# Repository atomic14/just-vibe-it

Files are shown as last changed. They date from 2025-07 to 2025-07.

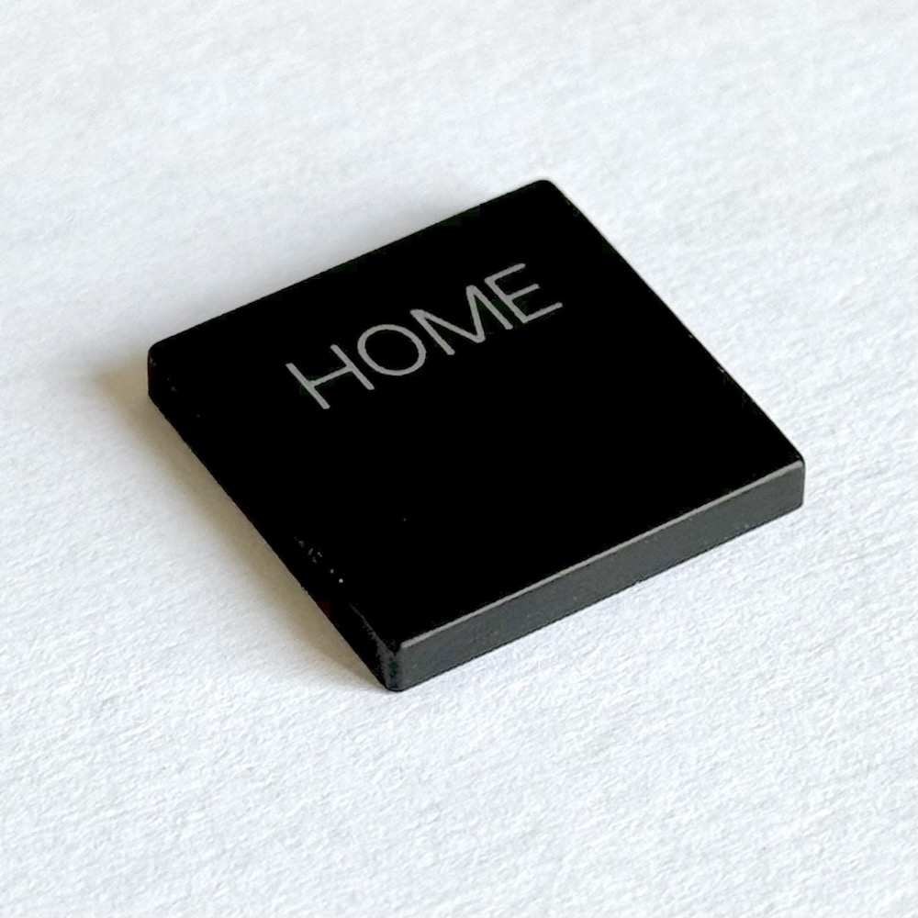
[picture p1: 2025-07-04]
hardware/Cherry_MX_ULP-main/Mistel_Air_One.jpeg

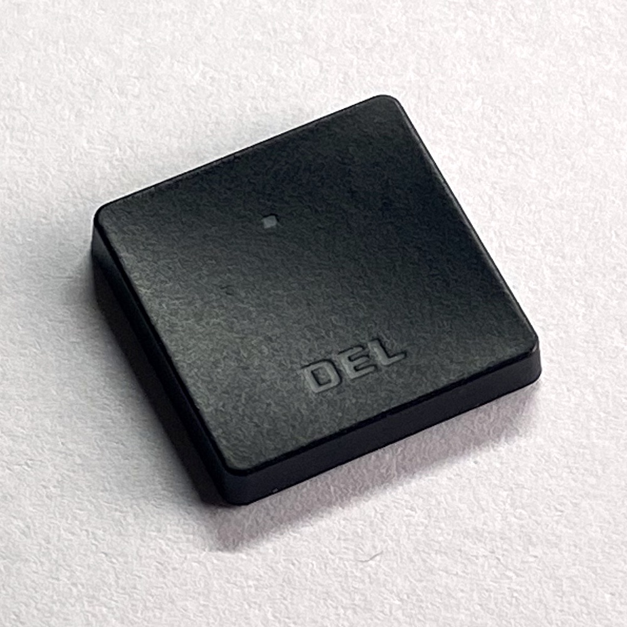
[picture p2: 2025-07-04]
hardware/Cherry_MX_ULP-main/Corsair_K100_Air.jpeg

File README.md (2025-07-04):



# Vibetastic - Single Key Keyboard

Vibetastic Demo (https://youtu.be/SV0bM1FkdLY)

*Click the image above to watch the demo video*

## Overview

A very silly but functional single-key keyboard - perfect for vibe coding! This project combines interesting hardware design choices with AI-assisted firmware development.

## Key Features

- **Dual Power Management**: Uses TPS2117 for clean switching between battery and USB power with controlled slew rate
- **Versatile Switch Compatibility**: Custom PCB footprint supports both low-profile and full-height Cherry MX switches
- **Stabilizer Support**: Full-height keycaps can use stabilizers for improved feel and reduced wobble
- **AI-Coded Firmware**: The entire codebase was developed through AI collaboration without manual code review

## Hardware Highlights

The PCB incorporates several thoughtful design decisions:
- TPS2117 power switch controller enables high capacitance loads without violating USB specifications
- Hybrid Cherry MX footprint accommodates both switch types (though stabilizers only work with full-height switches)
- Clean power management replaces traditional MOSFET/diode circuits

## Project Structure

- `/firmware/` - PlatformIO-based embedded firmware
- `/hardware/` - KiCad PCB design files and component libraries

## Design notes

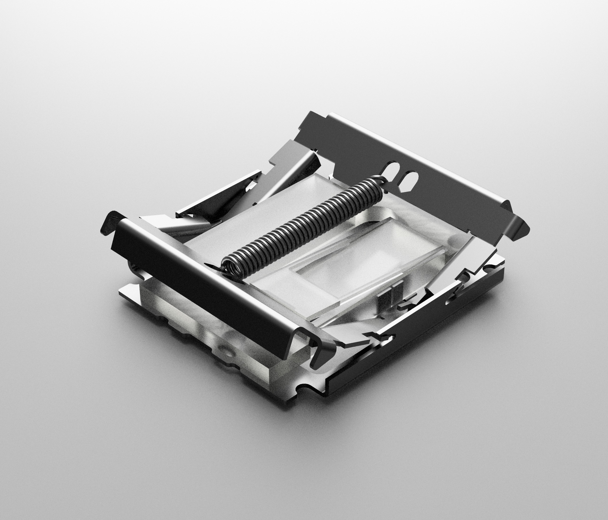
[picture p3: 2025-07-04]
hardware/Cherry_MX_ULP-main/Cherry_MX_ULP.jpg

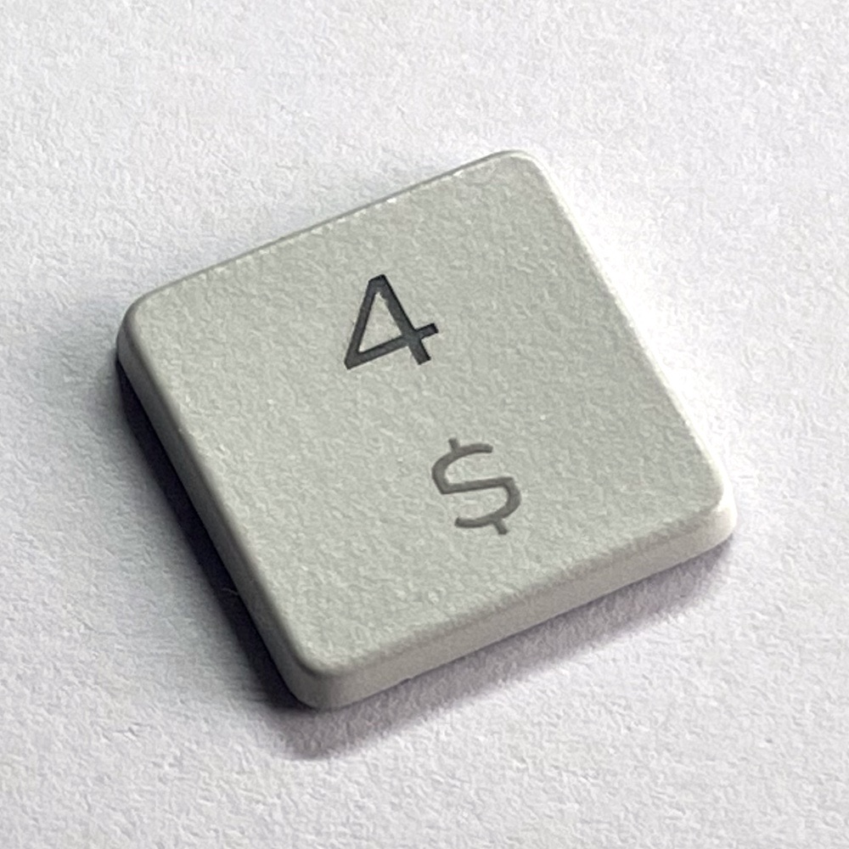
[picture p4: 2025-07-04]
hardware/Cherry_MX_ULP-main/Dell_Module.jpeg

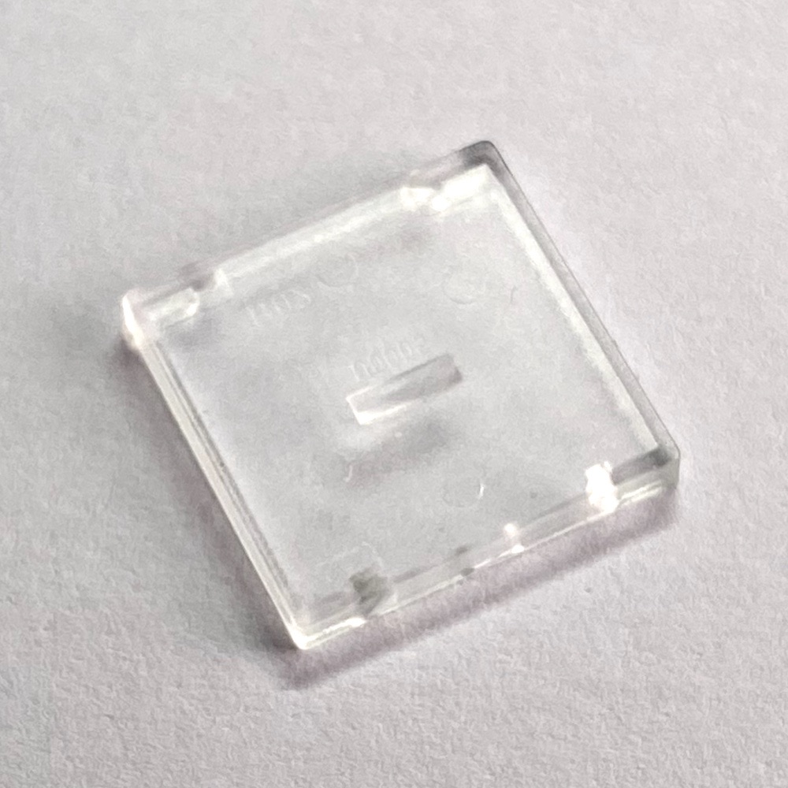
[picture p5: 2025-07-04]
hardware/Cherry_MX_ULP-main/Cherry_Early_Prototype.jpeg

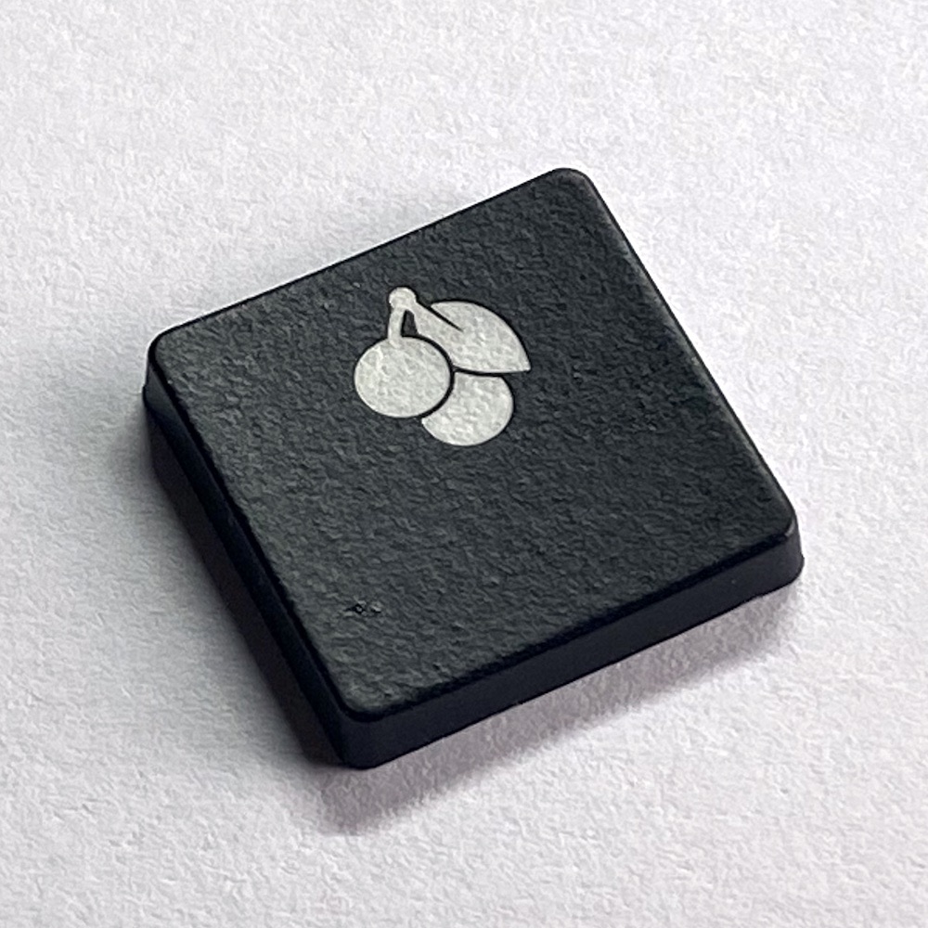
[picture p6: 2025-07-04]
hardware/Cherry_MX_ULP-main/Cherry_KW_x_ULP.jpeg

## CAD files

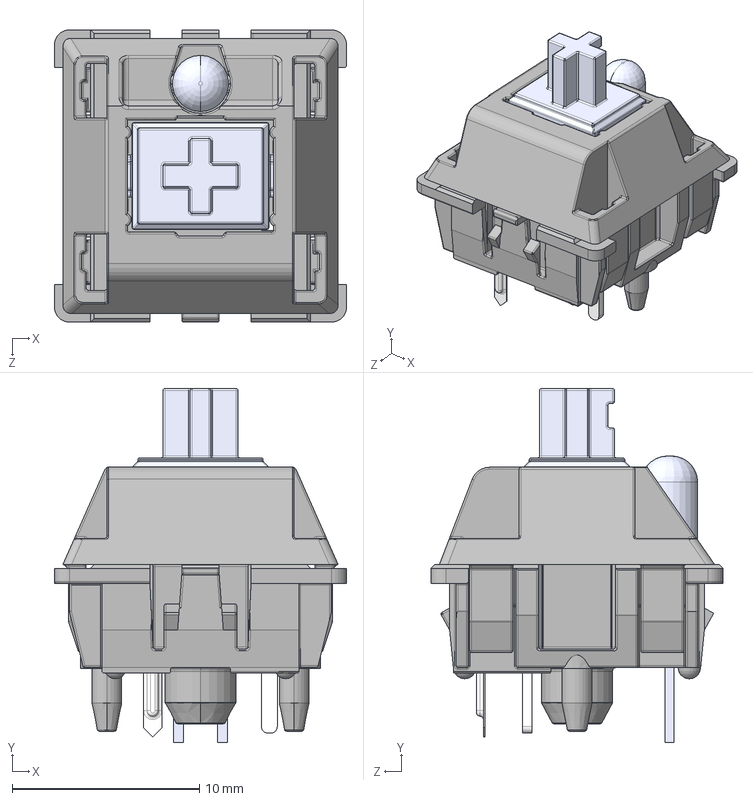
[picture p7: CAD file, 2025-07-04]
hardware/3d-models/MX .STEP
15.6 x 18.9 x 15.6 mm
MX 轴 按键′_ü___¨1
MX 轴 轴体áì_¨￠¨__
MX粣 拸簽LEDLEDLED
MX轴 轴体 底部 μ×2__默认_á2____è_
针脚___默认__è_

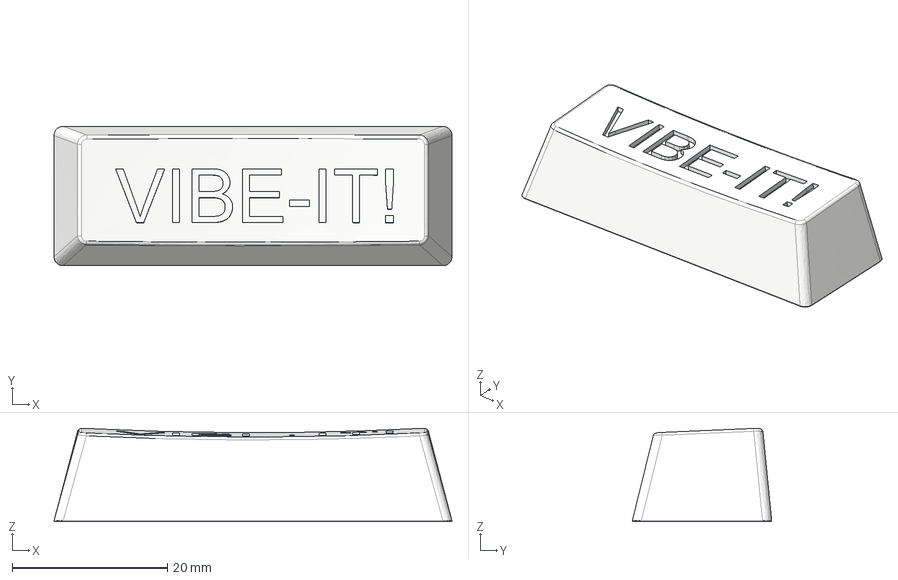
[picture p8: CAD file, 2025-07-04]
hardware/3d-models/keycap.step
51.3 x 18.0 x 12.0 mm

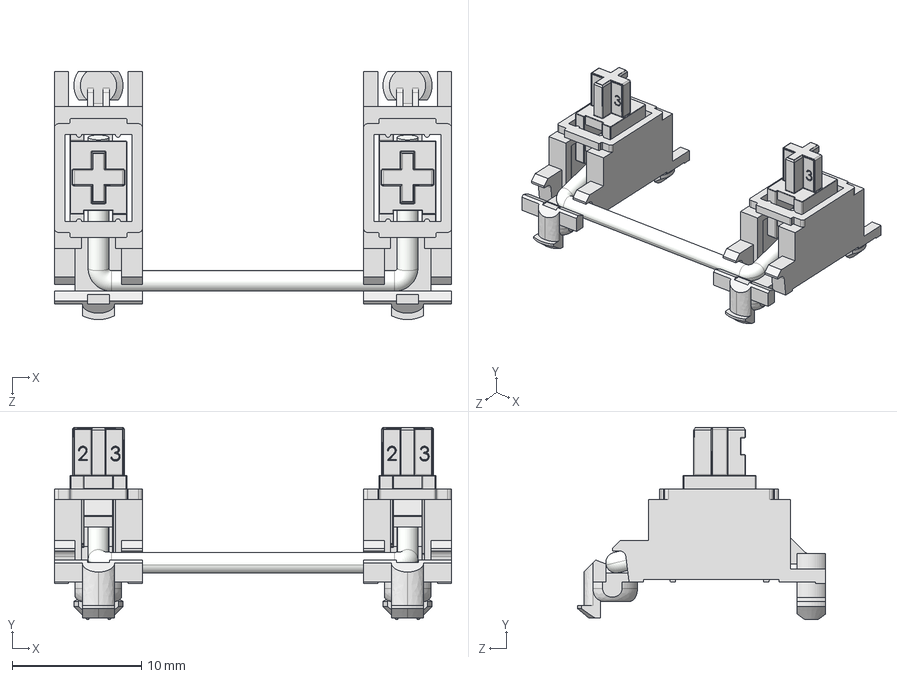
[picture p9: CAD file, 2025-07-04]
hardware/3d-models/Stabilizer - close.STEP
30.7 x 14.9 x 19.2 mm
mx Stabilizer base 16828 x 2
mx Stabilizer key 16828 x 2
metal stick 16828

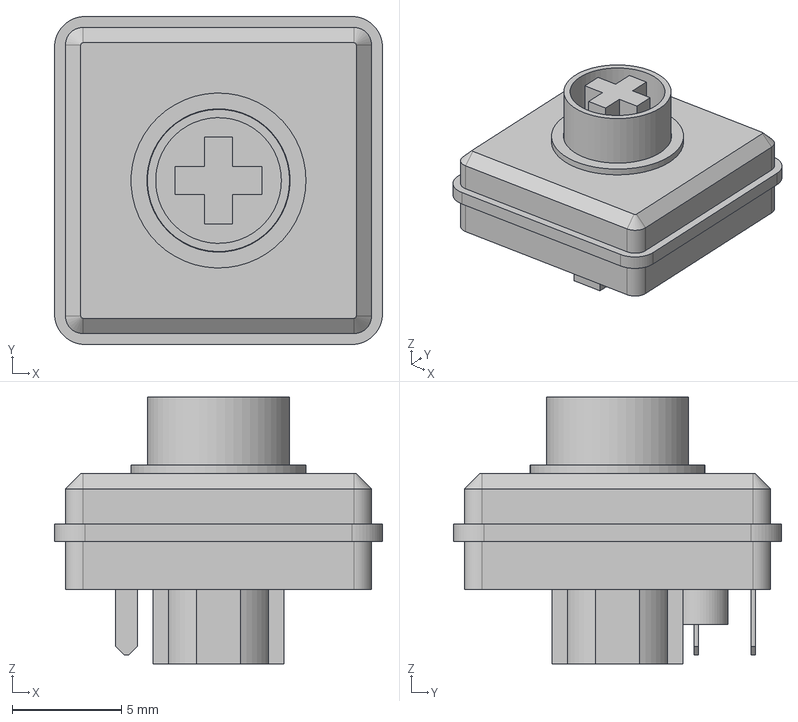
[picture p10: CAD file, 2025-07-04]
hardware/3d-models/[low detail] Low Profile Cherry MX Red.step
15.0 x 15.0 x 12.2 mm

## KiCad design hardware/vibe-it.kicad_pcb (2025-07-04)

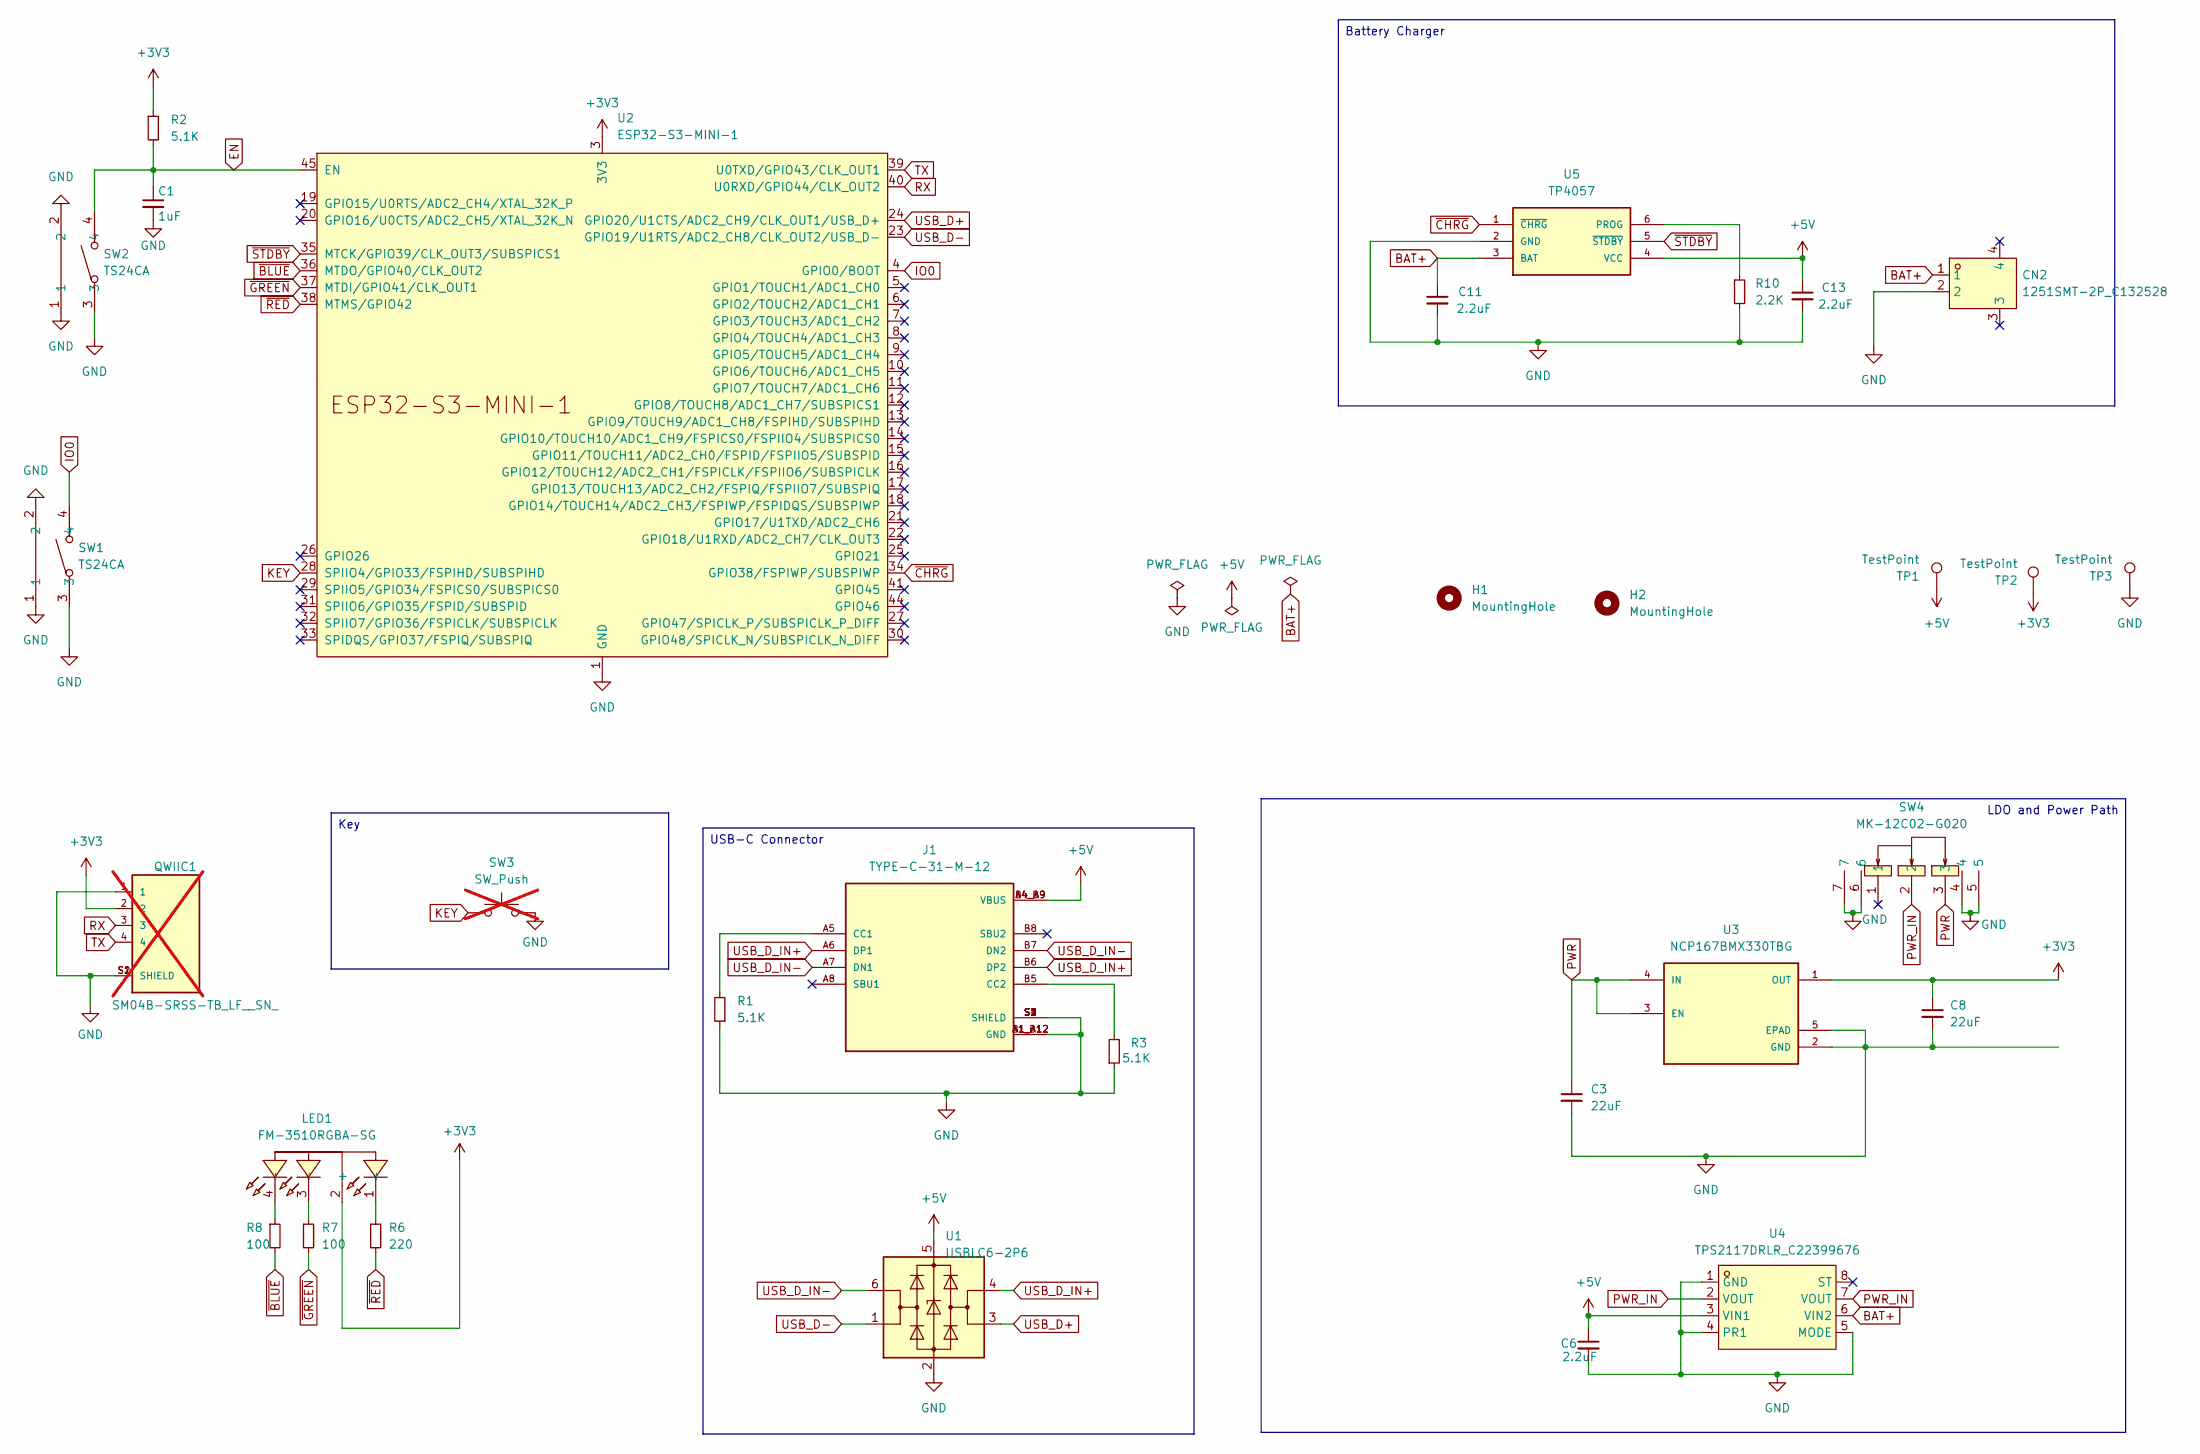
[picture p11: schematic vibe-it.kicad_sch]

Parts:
C1: 1uF; C_0603_1608Metric
C3, C8: 22uF; C_0603_1608Metric
C6: 2.2uF; C_0603_1608Metric; Mfg Part # test
C11, C13: 2.2uF; C_0603_1608Metric
CN2: 1251SMT-2P_C132528; CONN-SMD_1251SMT-2P; LCSC Part C132528
H1, H2: MountingHole; MountingHole_2.2mm_M2
J1: TYPE-C-31-M-12; HRO_TYPE-C-31-M-12; PARTREV 2020.12.08
LED1: FM-3510RGBA-SG; LED-SMD_FM-3510RGBA-SG; LCSC Part C727903
QWIIC1: SM04B-SRSS-TB_LF__SN_; JST_SM04B-SRSS-TB_LF__SN_; not fitted
R1, R2, R3: 5.1K; R_0603_1608Metric
R6: 220; R_0603_1608Metric
R7, R8: 100; R_0603_1608Metric
R10: 2.2K; R_0603_1608Metric
SW1, SW2: TS24CA; SW-SMD_TS24CA; LCSC Part C393942
SW3: SW_Push; Cherry-combined-low-mx; not fitted
SW4: MK-12C02-G020; SW-SMD_MK-12C02-G020; LCSC Part C963206
TP1, TP2, TP3: TestPoint; TestPoint_Pad_D2.0mm
U1: USBLC6-2P6; SOT-666
U2: ESP32-S3-MINI-1
U3: NCP167BMX330TBG; VREG_NCP167BMX330TBG; PARTREV 5
U4: TPS2117DRLR_C22399676; SOT-583-8; LCSC Part C22399676
U5: TP4057; SOT-23-6

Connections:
+3V3: C8.1, LED1.2 (+), QWIIC1.2, R2.1, TP2.1, U2.3 (3V3), U3.1 (OUT)
+5V: C6.1, C13.1, J1.A4_B9 (VBUS), J1.B4_A9 (VBUS), TP1.1, U1.5 (VBUS), U4.3 (VIN1), U5.4 (VCC)
BAT+: C11.1, CN2.1, U4.6 (VIN2), U5.3 (BAT)
EN: C1.1, R2.2, SW2.4, U2.45 (EN)
GND: C1.2, C3.2, C6.2, C8.2, C11.2, C13.2, CN2.2, J1.A1_B12 (GND), J1.B1_A12 (GND), J1.S1 (SHIELD), J1.S2 (SHIELD), J1.S3 (SHIELD), J1.S4 (SHIELD), QWIIC1.1, QWIIC1.S1 (SHIELD), QWIIC1.S2 (SHIELD), R1.1, R3.1, R10.2, SW1.1, SW1.2, SW1.3, SW2.1, SW2.2, SW2.3, SW3.2, SW4.4, SW4.5, SW4.6, SW4.7, TP3.1, U1.2 (GND), U2.1 (GND), U2.2 (GND), U2.42 (GND), U2.43 (GND), U2.46 (GND), U2.47 (GND), U2.48 (GND), U2.49 (GND), U2.50 (GND), U2.51 (GND), U2.52 (GND), U2.53 (GND), U2.54 (GND), U2.55 (GND), U2.56 (GND), U2.57 (GND), U2.58 (GND), U2.59 (GND), U2.60 (GND), U2.61 (GND), U2.62 (GND), U2.63 (GND), U2.64 (GND), U2.65 (GND), U3.2 (GND), U3.5 (EPAD), U4.1 (GND), U4.4 (PR1), U4.5 (MODE), U5.2 (GND)
IO0: SW1.4, U2.4 (GPIO0/BOOT)
KEY: SW3.1, U2.28 (SPIIO4/GPIO33/FSPIHD/SUBSPIHD)
unnamed: J1.A5 (CC1), R1.2
unnamed: J1.B5 (CC2), R3.2
unnamed: LED1.1 (-), R6.1
unnamed: LED1.3 (-), R7.1
unnamed: LED1.4 (-), R8.1
unnamed: R10.1, U5.6 (PROG)
PWR: C3.1, SW4.3, U3.3 (EN), U3.4 (IN)
PWR_IN: SW4.2, U4.2 (VOUT), U4.7 (VOUT)
RX: QWIIC1.3, U2.40 (U0RXD/GPIO44/CLK_OUT2)
TX: QWIIC1.4, U2.39 (U0TXD/GPIO43/CLK_OUT1)
USB_D+: U1.3 (I/O2), U2.24 (GPIO20/U1CTS/ADC2_CH9/CLK_OUT1/USB_D+)
USB_D-: U1.1 (I/O1), U2.23 (GPIO19/U1RTS/ADC2_CH8/CLK_OUT2/USB_D-)
USB_D_IN+: J1.A6 (DP1), J1.B6 (DP2), U1.4 (I/O2)
USB_D_IN-: J1.A7 (DN1), J1.B7 (DN2), U1.6 (I/O1)
~BLUE: R8.2, U2.36 (MTDO/GPIO40/CLK_OUT2)
~CHRG: U2.34 (GPIO38/FSPIWP/SUBSPIWP), U5.1 (~CHRG)
~GREEN: R7.2, U2.37 (MTDI/GPIO41/CLK_OUT1)
~RED: R6.2, U2.38 (MTMS/GPIO42)
~STDBY: U2.35 (MTCK/GPIO39/CLK_OUT3/SUBSPICS1), U5.5 (~STDBY)

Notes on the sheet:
LDO and Power Path
Battery Charger
USB-C Connector
Key

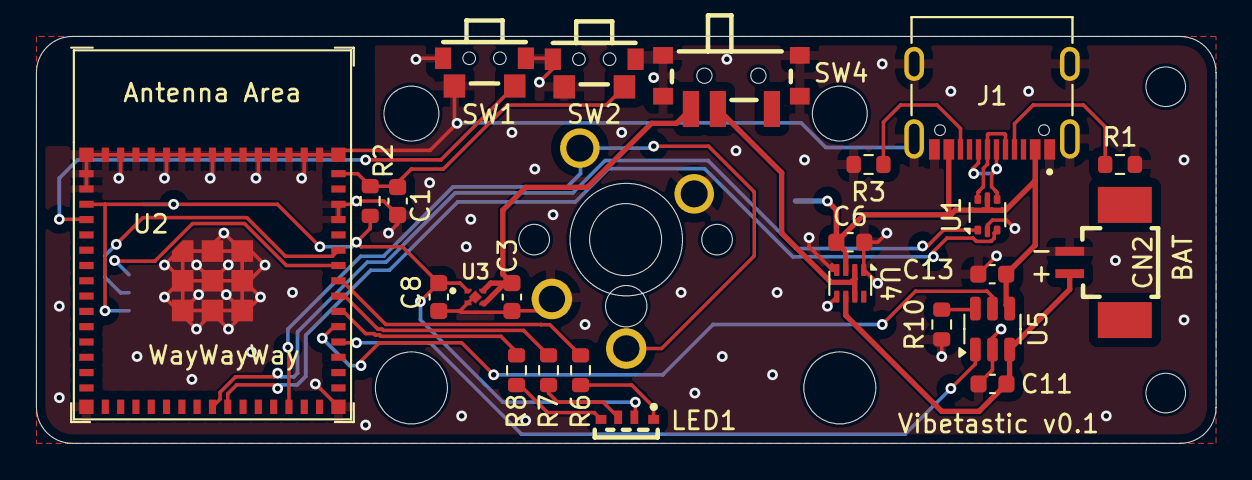
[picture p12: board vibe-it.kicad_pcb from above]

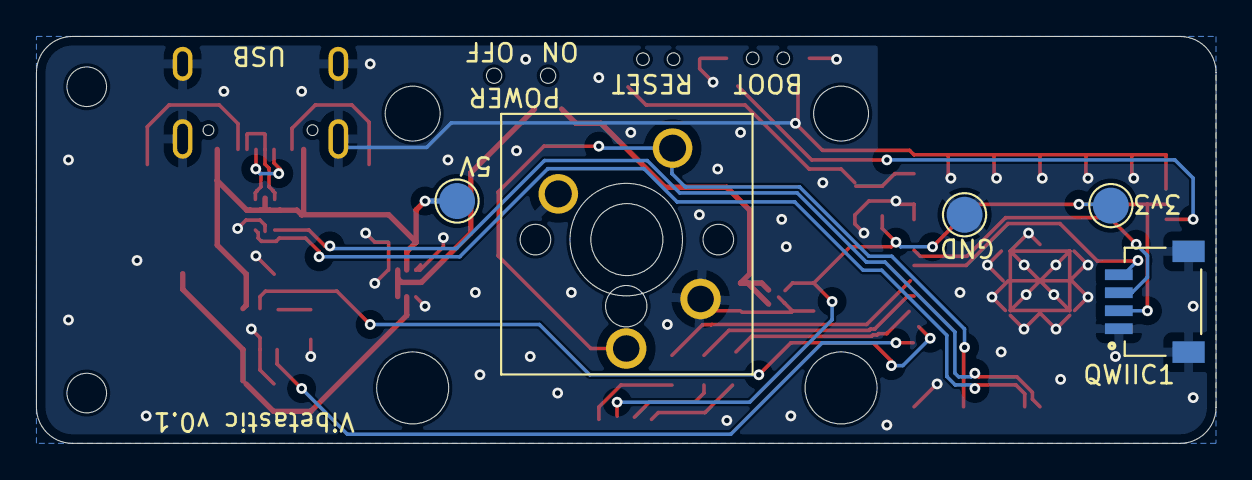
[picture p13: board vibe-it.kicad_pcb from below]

Board: 2 copper layers, 65.5 x 22.6 mm, 31 parts (5 on the bottom side), 26 nets.

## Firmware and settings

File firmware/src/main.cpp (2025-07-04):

#include <Arduino.h>
#include "hardware.h"
#include "USB.h"
#include "USBCDC.h"

// Include our custom classes
#include "ChargingStatusManager.h"
#include "KeyboardManager.h"
#include "ButtonManager.h"
#include "LEDManager.h"

// Create USB Serial instance
USBCDC SerialUSB;

// Create instances of our managers
ChargingStatusManager chargingManager;
KeyboardManager keyboardManager;
ButtonManager buttonManager;
LEDManager ledManager;

// Key state tracking
bool keysPressed = false;

void setup() {
    // Initialize USB and Serial for debugging
    USB.begin();
    SerialUSB.begin(115200);
    delay(5000); // Give serial time to initialize
    
    SerialUSB.println("=== INITIALIZING VIBETASTIC KEYBOARD ===");
    
    // Initialize all managers
    chargingManager.begin();
    keyboardManager.begin();
    buttonManager.begin();
    ledManager.begin();
    
    SerialUSB.println("=== DUAL MODE KEYBOARD READY ===");
    SerialUSB.println("USB: Always ready when plugged in");
    SerialUSB.println("BLE: Look for 'Vibetastic Keyboard' in Bluetooth settings");
    SerialUSB.println("Press and hold the key to send Command+ENTER on both USB and BLE");
    SerialUSB.println("LED Status:");
    SerialUSB.println("  Red (flashing) = Charging battery");
    SerialUSB.println("  Green (solid) = Battery fully charged");
    SerialUSB.println("  Blue (solid) = Key press indicator");
    SerialUSB.println("  Blue (3 flashes) = Startup complete");
    
    // Show ready indicator
    ledManager.showReadyIndicator();
    
    SerialUSB.println("Setup complete!");
    SerialUSB.println("Waiting for BLE connection...");
    SerialUSB.println("Charging status monitoring active...");
}

void loop() {
    // Update all managers
    chargingManager.update();
    
    // Check for button state changes
    if (buttonManager.update()) {
        if (buttonManager.isPressed()) {
            if (!keysPressed) {
                keyboardManager.pressCommandEnter();
                ledManager.setKeyPressIndicator(true);
                keysPressed = true;
            }
        } else {
            if (keysPressed) {
                keyboardManager.releaseCommandEnter();
                ledManager.setKeyPressIndicator(false);
                keysPressed = false;
            }
        }
    }
    
    // Small delay to prevent excessive CPU usage
    delay(10);
}

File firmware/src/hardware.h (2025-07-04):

#ifndef VIBE_IT_PINS_H
#define VIBE_IT_PINS_H

#include <Arduino.h>
#include "USBCDC.h"

// External USB Serial instance (defined in main.cpp)
extern USBCDC SerialUSB;

/*
 * This header file contains the pinout definitions for the vibe-it hardware.
 *
 * It is based on the provided BOM and netlist files.
 *
 * Netlist dated: 2025-07-01
 *
 */

// --- Switches ---

// The main key switch (SW3) 
// Connects to ground when pressed, so an internal pull-up is required. 
#define KEY_SWITCH_PIN 33 

// The boot switch (SW1) 
// Connects to ground when pressed. For normal operation, an internal pull-up is required. 
// Holding this low on boot enters the bootloader.
#define BOOT_SWITCH_PIN 0

// The reset/enable switch (SW2) is connected to the ESP32's EN pin. 
// It is externally pulled up by R2, so no internal pull-up is needed. 


// --- RGB LED ---

// The RGB LED (LED1) is a common anode LED. 
// The GPIOs are connected to the cathodes through current-limiting resistors.
// A 'LOW' signal will turn the respective color on.

#define LED_RED_PIN 42    // Connected to R6 
#define LED_GREEN_PIN 41  // Connected to R7 
#define LED_BLUE_PIN 40   // Connected to R8 


// --- Battery Charger (U5 - TP4057) ---

// The ~CHRG pin is an open-collector output. It is LOW when charging. 
// An internal pull-up is required to read the state.
#define CHARGE_STATUS_PIN 38

// The ~STDBY pin is an open-collector output. It is LOW when charging is complete (standby). 
// An internal pull-up is required to read the state.
#define STANDBY_STATUS_PIN 35


// --- QWIIC Connector (QWIIC1) ---

// UART pins for the QWIIC connector
#define QWIIC_TX_PIN 43 // Connected to U2 pin 39 
#define QWIIC_RX_PIN 44 // Connected to U2 pin 40 


// --- USB ---

// Onboard USB data lines
#define USB_D_NEGATIVE_PIN 19 // Connected to U2 pin 23 
#define USB_D_POSITIVE_PIN 20 // Connected to U2 pin 24 


/*
 * Example setup function:
 *
 * void setup() {
 * // Initialize Switches with internal pull-ups
 * pinMode(KEY_SWITCH_PIN, INPUT_PULLUP);
 * pinMode(BOOT_SWITCH_PIN, INPUT_PULLUP);
 *
 * // Initialize LED pins as outputs
 * pinMode(LED_RED_PIN, OUTPUT);
 * pinMode(LED_GREEN_PIN, OUTPUT);
 * pinMode(LED_BLUE_PIN, OUTPUT);
 *
 * // Set default LED state to OFF (HIGH for common anode)
 * digitalWrite(LED_RED_PIN, HIGH);
 * digitalWrite(LED_GREEN_PIN, HIGH);
 * digitalWrite(LED_BLUE_PIN, HIGH);
 *
 * // Initialize Battery Charger status pins with internal pull-ups
 * pinMode(CHARGE_STATUS_PIN, INPUT_PULLUP);
 * pinMode(STANDBY_STATUS_PIN, INPUT_PULLUP);
 * }
 */

#endif // VIBE_IT_PINS_H
